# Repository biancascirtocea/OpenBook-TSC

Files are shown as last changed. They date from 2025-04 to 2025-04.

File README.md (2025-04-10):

# OpenBook Reader

## Descriere generala

Proiectul **OpenBook ESP32-C6** este o platforma hardware compacta si portabila, dedicata aplicatiilor embedded cu consum redus de energie. Este construit in jurul microcontrollerului **ESP32-C6-WROOM-1-N8**, oferind conectivitate wireless (Wi-Fi 6 si BLE 5.0) si numeroase interfete pentru senzori si module externe. Platforma include un e-paper display, senzor de mediu BME688, modul RTC DS3231SN, memorie externa NOR Flash de 64MB, slot pentru SD card si sistem de alimentare cu baterie LiPo cu incarcator si indicator de nivel.

---

## Diagramă bloc

430666922-ddbbfbfa-e72c-47d6-83a7-a39f880fc3e8

---

## BOM - Bill of Materials

# BOM (Bill Of Materials)

| Componenta | Link | Datasheet |
|---|---|---|
| BUTTON | [Model](https://industry.panasonic.com/global/en/products/control/switch/light-touch/number/evqpuj02k) | [Datasheet](https://www.lcsc.com/datasheet/lcsc_datasheet_2201121800_PANASONIC-EVQPUJ02K_C2936858.pdf) |
| CAPACITOR | [Model](https://componentsearchengine.com/part-view/R0402%201%25%20100%20K%20(RC0402FR-07100KL)/YAGEO) | [Datasheet](//efaidnbmnnnibpcajpcglclefindmkaj/https://www.resistor.com/assets/pdf/0402tstd.pdf) |
| CPH3225A | [Model](https://www.snapeda.com/parts/CPH3225A/Seiko+Instruments/view-part/?ref=eda) | [Datasheet](https://octopart.com/datasheet/cph3225a-seiko-25340571) |
| EVQPUJ02K | [Model](https://industry.panasonic.com/global/en/products/control/switch/light-touch/number/evqpuj02k) | [Datasheet](https://www.lcsc.com/datasheet/lcsc_datasheet_2201121800_PANASONIC-EVQPUJ02K_C2936858.pdf) |
| KP-1608SURCK | [Model](https://www.snapeda.com/parts/KP-1608SURCK/Kingbright/view-part/?ref=search&t=LED%200603) | [Datasheet](//efaidnbmnnnibpcajpcglclefindmkaj/https://media.elv.com/file/107153_led_surck1608_data.pdf) |
| USBLC6-2SC6Y | [Model](https://www.snapeda.com/parts/USBLC6-2SC6Y/STMicroelectronics/view-part/?ref=eda) | [Datasheet](https://www.digikey.com/en/htmldatasheets/production/1375342/0/0/1/usblc6-2sc6y) |
| SD0805S020S1R0 | [Model](https://ro.mouser.com/ProductDetail/KYOCERA-AVX/SD0805S020S1R0?qs=jCA%252BPfw4LHbpkAoSnwrdjw%3D%3D) | [Datasheet](https://www.alldatasheet.com/view.jsp?Searchword=SD0805S&sField=2) |
| PGB1010603MR | [Model](https://www.snapeda.com/parts/PGB1010603MR/Littelfuse/view-part/?ref=eda) | [Datasheet](https://www.alldatasheet.com/view.jsp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) |
| BD5229G-TR  | [Model](https://componentsearchengine.com/part-view/BD5229G-TR/ROHM%20Semiconductor) | [Datasheet](https://www.lcsc.com/datasheet/lcsc_datasheet_2201131330_ROHM-Semicon-BD5229G-TR_C962636.pdf) |
| XC6220A331MR-G | [Model](https://componentsearchengine.com/part-view/XC6220A331MR-G/Torex) | [Datasheet](https://www.alldatasheet.com/view.jsp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) |
| XC6220A331MR-G | [Model](https://componentsearchengine.com/part-view/XC6220A331MR-G/Torex) | [Datasheet](https://www.alldatasheet.com/view.jsp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) |
| USB4110-GF-A  | [Model](https://componentsearchengine.com/part-view/USB4110-GF-A/GCT%20(GLOBAL%20CONNECTOR%20TECHNOLOGY)) | [Datasheet](//efaidnbmnnnibpcajpcglclefindmkaj/https://gct.co/files/drawings/usb4110.pdf) |
| Adafruit | [Model](https://eu.mouser.com/ProductDetail/Adafruit/4208?qs=PzGy0jfpSMtbScLbr0L5dw%3D%3D) | [Datasheet](https://www.arrow.com/en/manufacturers/adafruit-industries/datasheets) |
| Bobina | [Model](https://store.comet.srl.ro/Catalogue/Product/43497/) | [Datasheet](https://www.scribd.com/document/814581278/Datasheet-Bobina) |
| PFMF | [Model](https://www.mouser.co.uk/ProductDetail/EPCOS-TDK/B72520T0350K062?qs=dEfas%2FXlABIszF52uu7vrg%3D%3D) | [Datasheet](https://ro.mouser.com/c/ds/circuit-protection/thermistors/resettable-fuses-pptc/?m=Schurter&series=PFMF) |
| DMG2305UX-7 | [Model](https://componentsearchengine.com/part-view/DMG2305UX-7/Diodes%20Incorporated) | [Datasheet](//efaidnbmnnnibpcajpcglclefindmkaj/https://www.mouser.com/datasheet/2/115/DMG2305UX-266242.pdf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) |
| Si1308EDL-T1-GE3 | [Model](https://componentsearchengine.com/part-view/SI1308EDL-T1-GE3/Vishay) | [Datasheet](https://www.alldatasheet.com/view.jsp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) |
| R0402 | [Model](https://componentsearchengine.com/part-view/R0402%201%25%20100%20K%20(RC0402FR-07100KL)/YAGEO) | [Datasheet](//efaidnbmnnnibpcajpcglclefindmkaj/https://www.resistor.com/assets/pdf/0402tstd.pdf) |
| BME680 | [Model](https://www.snapeda.com/parts/BME680/Bosch/view-part/?welcome=home) | [Datasheet](//efaidnbmnnnibpcajpcglclefindmkaj/https://www.bosch-sensortec.com/media/boschsensortec/downloads/datasheets/bst-bme680-ds001.pdf) |
| SMD Solder | [Model](https://grabcad.com/library/solder-jumpers-1) | [Datasheet]() |
| W25Q512JVEIQ | [Model](https://www.snapeda.com/parts/ESP32-C6-WROOM-1-N8/Espressif+Systems/view-part/?ref=eda) | [Datasheet](//efaidnbmnnnibpcajpcglclefindmkaj/https://www.mouser.com/datasheet/2/949/W25Q512JV_SPI_RevB_06252019_KMS-2487502.pdf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) |
| ESP32-C6-WROOM-1-N8 | [Model](https://www.snapeda.com/parts/ESP32-C6-WROOM-1-N8/Espressif+Systems/view-part/?ref=eda) | [Datasheet](//efaidnbmnnnibpcajpcglclefindmkaj/https://www.mouser.com/catalog/specsheets/Espressif_ESP32_C6_WROOM_1%20_Datasheet_V0.1_PRELIMINARY_en.pdf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) |
| DS3231SN# | [Model](https://www.snapeda.com/parts/DS3231SN%23/Analog+Devices/view-part/?ref=eda) | [Datasheet](https://www.alldatasheet.com/view.jsp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) |
| MAX17048G+T10 | [Model](https://www.snapeda.com/parts/MAX17048G+T10/Analog+Devices/view-part/?ref=eda) | [Datasheet](https://www.alldatasheet.com/view.jsp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) |
| MCP73831T-5ACI/OT | [Model](https://www.mouser.co.uk/ProductDetail/Microchip-Technology/MCP73831T-5ACI-OT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) | [Datasheet](//efaidnbmnnnibpcajpcglclefindmkaj/https://ww1.microchip.com/downloads/en/DeviceDoc/MCP73831-Family-Data-Sheet-DS20001984H.pdf) |

---

## Functionalitate Hardware

### ESP32-C6:
ESP32-C6 este unitatea centrală de procesare responsabilă pentru toate operațiunile sistemului, comunicarea cu senzorii și modulele, și gestionarea energiei. (Frecvență - 160 MHz)

- Microcontroller principal, gestioneaza toate perifericele.
- Comunicatii: Wi-Fi 6, BLE 5.0
- GPIO-uri multiple configurabile pentru I2C, SPI, UART.
Arhitectură: RISC-V 32-bit

### RTC - DS3231SN:
- Timp real precis,chiar si cand este sistemul oprit, compensare de temperatură, baterie de backup
- I2C comun cu BME688.

### Senzor BME688:
- Masoara temperatura, umiditate, presiune si VOC (gaze).
- I2C: conectat la aceeasi magistrala cu RTC.
- Monitorizarea condițiilor ambientale pentru ajustarea automată a afișajului și urmărirea datelor de mediu

### E-Paper Display:
- Afișaj pasiv cu consum foarte redus.
- Control prin SPI + pini de control (RST, DC, BUSY).
- Dimensiune: 7.5 inches
- Resolutie: 800x480 pixels

### Memorie NOR Flash 64MB:
- W25Q512JVEIQ - memorie externa SPI pentru loguri sau grafica e-paper.
- Memorie externă pentru loguri sau stocare grafică e-paper

### Slot SD Card:
- Alternativa pentru stocare loguri mari.
- Controlat tot prin SPI (CS separat).
- Memorie Flash externă: W25Q512JVEIQ - 64MB NOR Flash
- Memorie externă pentru loguri sau stocare grafică e-paper

### Sistem de alimentare:
- Intrare USB-C + protecție ESD.
- Capacitate: 3.7V, minim 1500mAh
- MCP73831 pentru incarcarea bateriei LiPo.
- MAX17048 pentru citire nivel incarcare baterie (via I2C).
- Tensiune de intrare: 5V prin conector USB-C
- Regulator de tensiune: LDO pentru stabilizare la 3.3V.

### Conector USB-C și Protecție ESD
- Funcționalitate: Asigură alimentarea cu energie și capacitatea de transfer de date
- Protecție: Protecție ESD integrată și diodă Schottky pentru siguranța la polaritate inversă

###  Butoane și Interfața Utilizator
- Butoane tactile pentru navigare și control.

### Extensii:
- Header Qwiic pentru conectarea de senzori I2C plug-and-play.
- Posibilitate de extindere prin interfețele GPIO disponibile

### Interfețe de Comunicare
GPIO: Utilizat pentru controlul butoanelor și operațiuni generale I/O
SPI: Utilizat pentru cardul SD, memoria flash externă și afișajul e-paper
I2C: Utilizat pentru senzorul de mediu BME688 și modulul RTC DS3231SN
UART: Utilizat pentru debugging și comunicare serială
Wi-Fi și Bluetooth: Furnizate de ESP32-C6, permițând conectivitate wireless

## Supervisori de Tensiune și Reset
Circuit de monitorizare a tensiunii pentru reset sigur
Indicator nivel încărcare baterie

## Dimensiuni și Specificații Fizice
Dimensiuni placă PCB: aproximativ 92 x 54 mm
Formă: PCB cu design compact și eficient pentru integrare în carcasă

## Caracteristici Principale
Consum ultra-redus de energie datorită afișajului e-paper și managementului avansat al energiei
Conectivitate wireless completă prin Wi-Fi 6 și Bluetooth 5.0
Monitorizare a condițiilor de mediu în timp real
Design modular pentru extindere ușoară și personalizare
Suport pentru stocare externă prin card microSD
Autonomie extinsă a bateriei

## Caracteristici Software
Compatibil cu diverse formate de cărți electronice
Interfață utilizator intuitivă pentru navigare și citire
Capacitate de sincronizare wireless cu dispozitive și servicii externe
Personalizare avansată a experienței de citire
Monitorizare și înregistrare a datelor de mediu

## Note de Design
Layout PCB optimizat pentru minimizarea interferențelor și maximizarea eficienței energetice.
Componente selectate pentru consum redus de energie și performanță fiabilă.
Soluții de protecție integrate pentru componente sensibile.
Design compact pentru portabilitate ridicată.

---

## Conexiuni catre ESP32-C6

| Pin ESP32-C6 | Funcție | Conectat la |
|---|---|---|
| IO0 (MOSI) | SPI MOSI | E-paper, SD Card, Flash |
| IO1 (MISO) | SPI MISO | SD Card, Flash |
| IO2 (CLK) | SPI CLK | Toate SPI devices |
| IO3 (CS) | SPI CS | E-paper Display |
| IO4 | SPI CS | W25Q512 NOR Flash |
| IO5 | SPI CS | SD Card |
| IO6 | I2C SDA | BME688, RTC, Fuel Gauge |
| IO7 | I2C SCL | BME688, RTC, Fuel Gauge |
| IO8 | Buton Boot | GND prin rezistor |
| IO10, IO11 | UART0 | Programare / Debug |
| EN | Enable MCU | Legat la 3V3 prin pullup |

## Alte Observatii
- PCB Layout: oferă separare clară între power și logică digitală.

- Posibil montaj în carcasă 3D: puncte de prindere pentru șuruburi M2 pe marginile PCB.

- Ajustări Footprint : Bobina 744043680 și U4 (MAX17048G+T10) au fost ajustate pentru a preveni erori DRC.

- Restricții de Rutare Power
  * Majoritatea traseelor de alimentare sunt pe stratul superior
  * Necesitate de rutare parțială pe stratul inferior pentru unele trasee de alimentare
  * Plan de masă prezent pe ambele straturi pentru reducerea zgomotului și îmbunătățirea integrității semnalului

- Plasarea Componentelor
  * Layout-ul respectă design-ul de referință pentru eficiență optimă
  * Bateria se potrivește perfect lângă PCB în interiorul carcasei

- Puncte de Test : Test pads prezente pentru debugging pe semnale SPI/I2C/Power

- Număr și Amplasare Via-uri : Designul include 0 vias-uri pe traseul de putere.

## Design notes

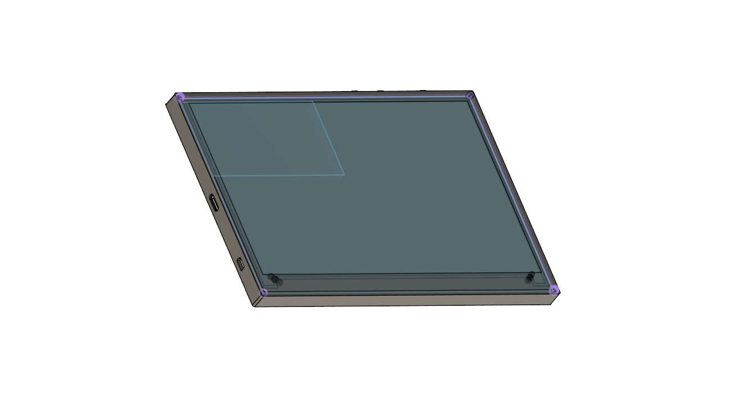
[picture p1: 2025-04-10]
Images/OpenBook_Reader_3D_Front2.png

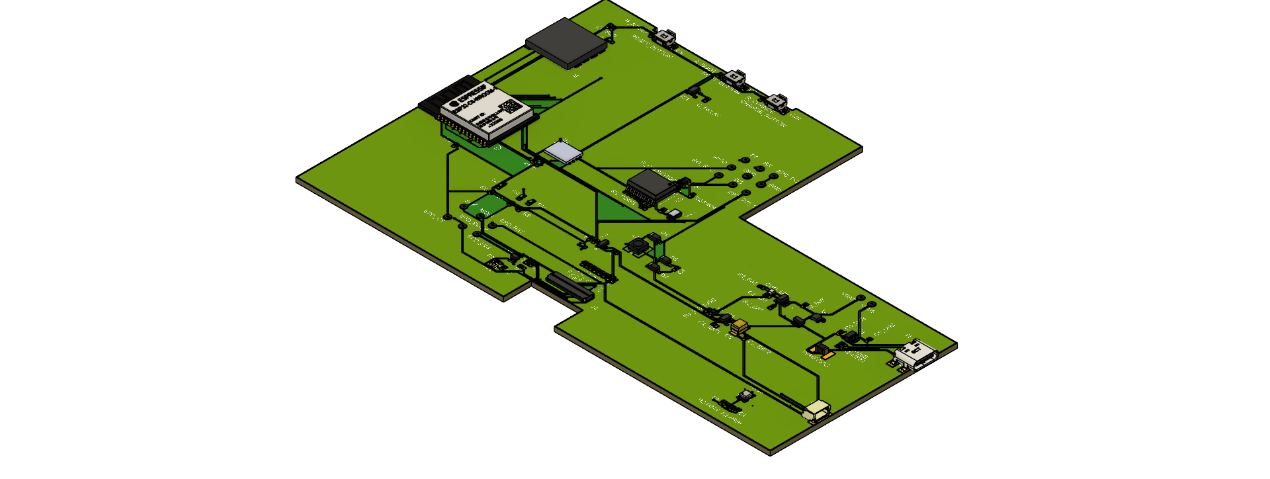
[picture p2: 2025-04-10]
Images/Face_3D_PCB.png

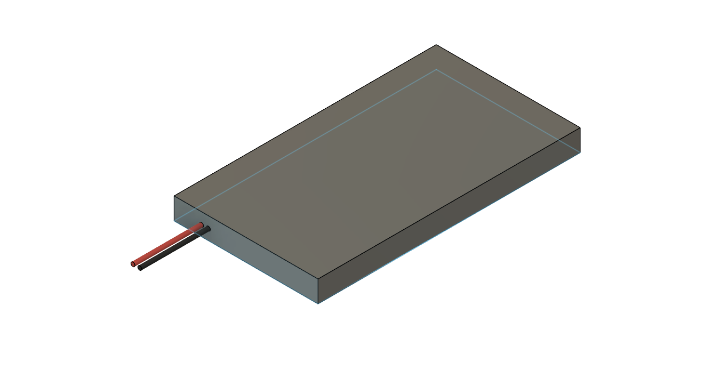
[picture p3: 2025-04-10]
Images/battery.png

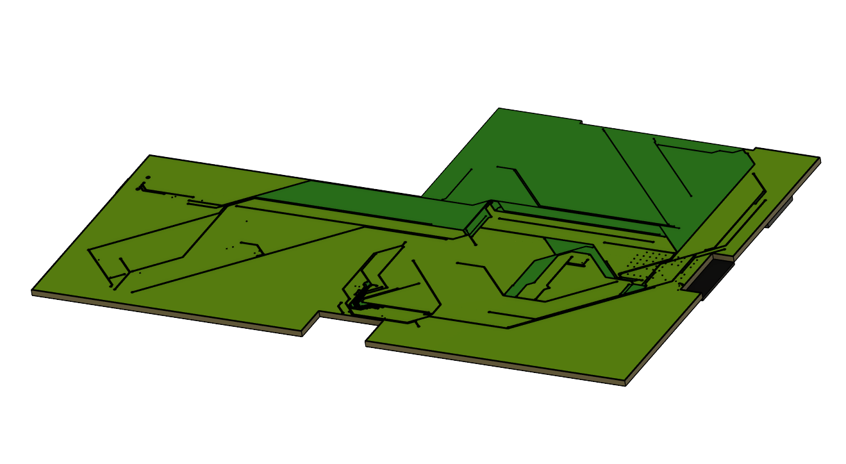
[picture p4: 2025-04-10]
Images/Back_3D_PCB.png

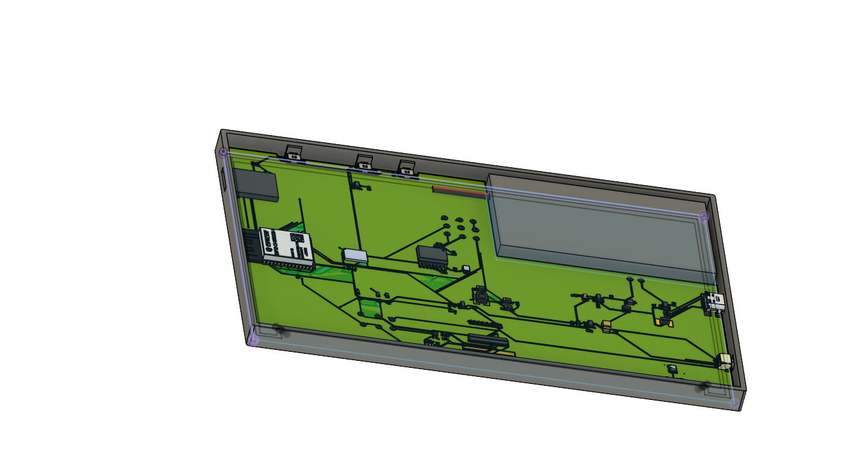
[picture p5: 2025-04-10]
Images/OpenBook_Reader_3D_Front1.png

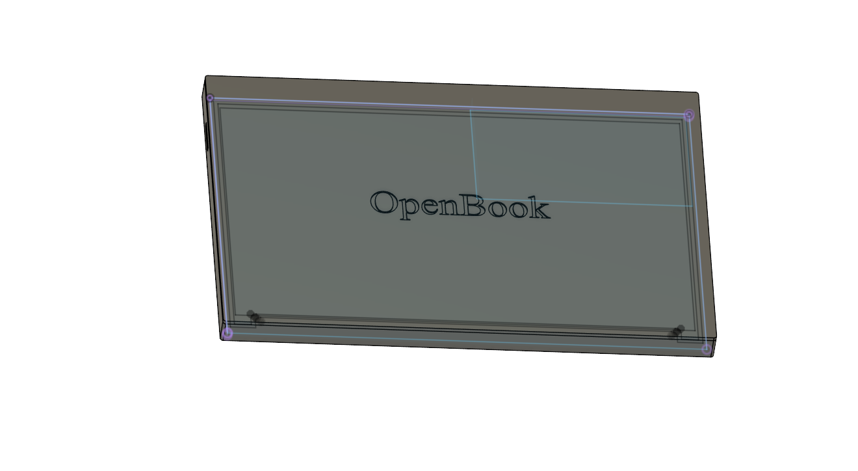
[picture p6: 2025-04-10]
Images/OpenBook_Reader_3D_Back2.png

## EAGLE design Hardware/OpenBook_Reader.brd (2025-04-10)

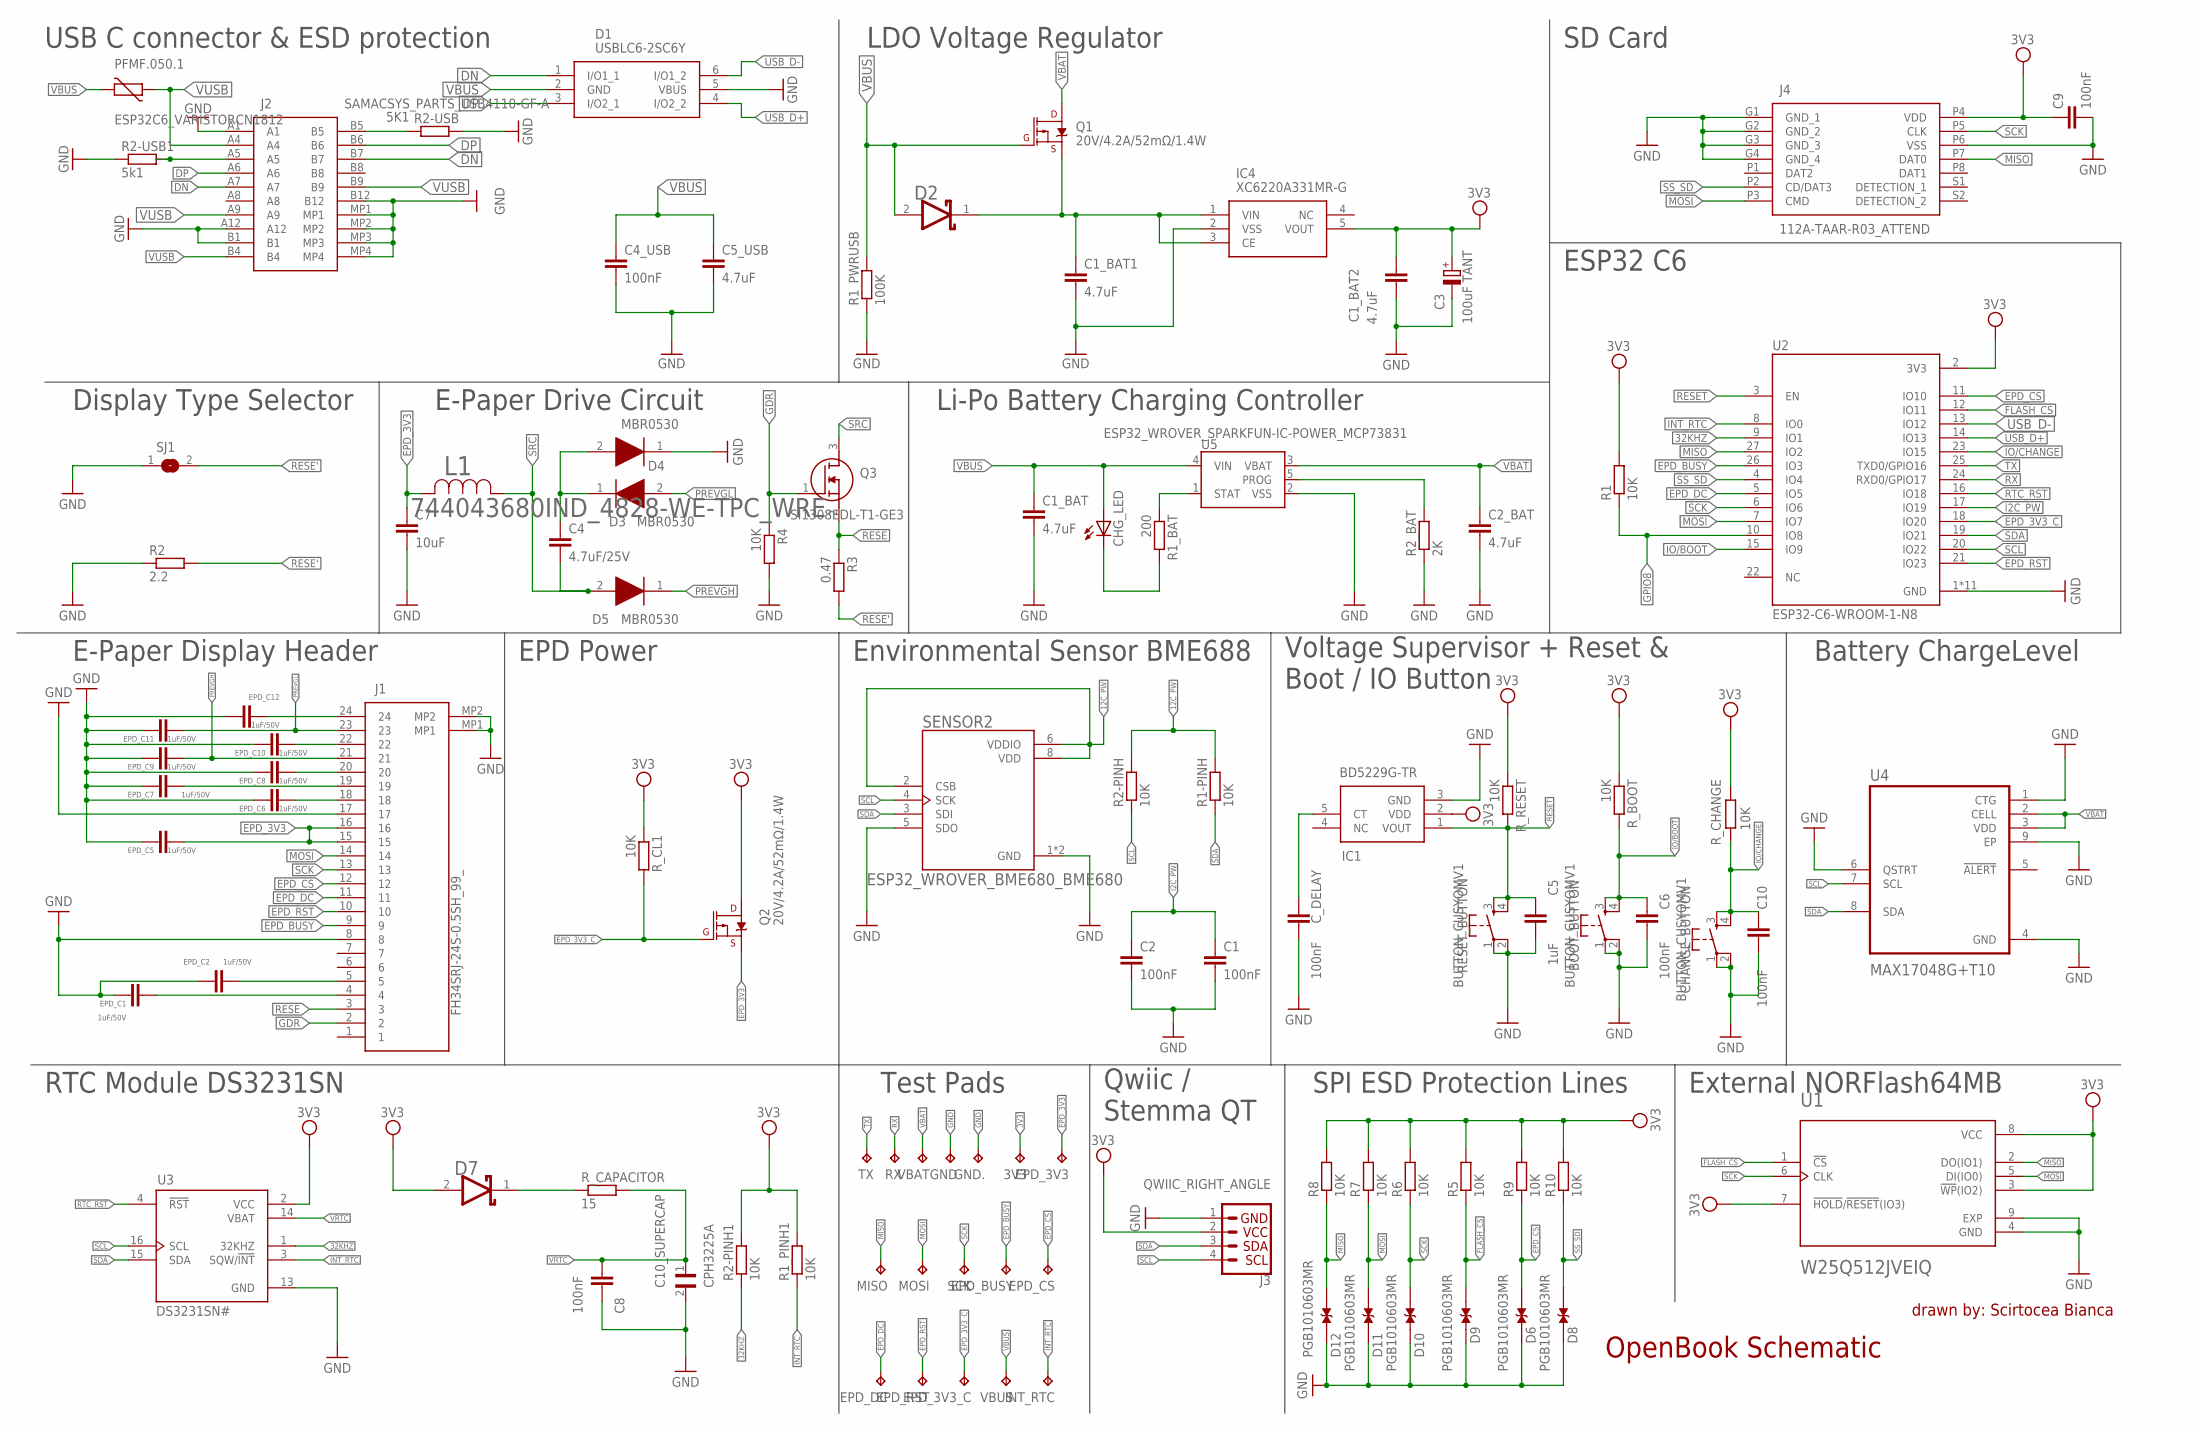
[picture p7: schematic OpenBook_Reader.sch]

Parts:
3V3: TPTP20R; TP20R
BOOT_BUTTON: BUTTON_CUSYOMV1; MYBUTTON
C1, C2, C4_USB, C6, C8, C9, C10: 100nF; EAGLE-LTSPICE_C0402
C1_BAT, C1_BAT1, C1_BAT2, C2_BAT, C5_USB: 4.7uF; EAGLE-LTSPICE_C0402
C3: 100uF TANT; RCL_CT3528
C4: 4.7uF/25V; EAGLE-LTSPICE_C0402
C5: 1uF; EAGLE-LTSPICE_C0402
C7: 10uF; EAGLE-LTSPICE_C0402
C10_SUPERCAP: CPH3225A; CAPCP3225X100N
CHANGE_BUTTON: BUTTON_CUSYOMV1; MYBUTTON
CHG_LED: ADAFRUIT_LEDCHIP-LED0603; ADAFRUIT_CHIP-LED0603
C_DELAY: 100nF; EAGLE-LTSPICE_C0402
D1: USBLC6-2SC6Y; SOT95P280X145-6N
D2, D7: ESP32_WROVER_AVX---SD0805S020S1R0_AVX_SD0805S020S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; ESP32_WROVER_AVX---SD0805S020S1R0_AVX_SD0805S020S1R0_0
D3, D4, D5: MBR0530; SOD3716X135N
D6, D8, D9, D10, D11, D12: PGB1010603MR; DIOC1608X36N
EPD_3V3, EPD_3V3_C: TPTP20R; TP20R
EPD_BUSY: TPTP20R; TP20R
EPD_C1, EPD_C2, EPD_C5, EPD_C6, EPD_C7, EPD_C8, EPD_C9, EPD_C10, EPD_C11, EPD_C12: 1uF/50V; EAGLE-LTSPICE_C0402
EPD_CS: TPTP20R; TP20R
EPD_DC: TPTP20R; TP20R
EPD_RST: TPTP20R; TP20R
GND, GND.: TPTP20R; TP20R
IC1: BD5229G-TR; SOT95P280X125-5N
IC4: XC6220A331MR-G; SOT95P280X120-5N
INT_RTC: TPTP20R; TP20R
J1: FH34SRJ-24S-0.5SH_99_; FH34SRJ24S05SH99
J2: SAMACSYS_PARTS_USB4110-GF-A; SAMACSYS_PARTS_USB4110GFA
J3: QWIIC_RIGHT_ANGLE; JST04_1MM_RA
J4: 112A-TAAR-R03_ATTEND; 112ATAARR03ATTEND
L1: 744043680IND_4828-WE-TPC_WRE; IND_4828-WE-TPC_WRE
MISO: TPTP20R; TP20R
MOSI: TPTP20R; TP20R
PFMF.050.1: ESP32C6_VARISTORCN1812; ESP32C6_VARISTOR_CT/CN1812
Q1, Q2: 20V/4.2A/52mΩ/1.4W; ESP32_WROVER_SPARKFUN-DISCRETESEMI_SOT23-3
Q3: SI1308EDL-T1-GE3; SOT65P210X110-3N
R1, R1-PINH, R1_PINH1, R2-PINH, R2-PINH1, R4, R5, R6, R7, R8, R9, R10: 10K; ESP32_WROVER_EAGLE-LTSPICE_R0402
R1_BAT: 200; ESP32_WROVER_EAGLE-LTSPICE_R0402
R1_PWRUSB: 100K; ESP32_WROVER_EAGLE-LTSPICE_R0402
R2: 2.2; ESP32_WROVER_EAGLE-LTSPICE_R0402
R2-USB: 5K1; ESP32_WROVER_EAGLE-LTSPICE_R0402
R2-USB1: 5k1; ESP32_WROVER_EAGLE-LTSPICE_R0402
R2_BAT: 2K; ESP32_WROVER_EAGLE-LTSPICE_R0402
R3: 0.47; ESP32_WROVER_EAGLE-LTSPICE_R0402
RESET_BUTTON: BUTTON_CUSYOMV1; MYBUTTON
RX: TPTP20R; TP20R
R_BOOT: 10K; ESP32_WROVER_EAGLE-LTSPICE_R0402
R_CAPACITOR: 15; ESP32_WROVER_EAGLE-LTSPICE_R0402
R_CHANGE: 10K; ESP32_WROVER_EAGLE-LTSPICE_R0402
R_CL1: 10K; ESP32_WROVER_EAGLE-LTSPICE_R0402
R_RESET: 10K; ESP32_WROVER_EAGLE-LTSPICE_R0402
SCK: TPTP20R; TP20R
SENSOR2: ESP32_WROVER_BME680_BME680; ESP32_WROVER_BME680_PSON80P300X300X100-8N
SJ1: SJ
TX: TPTP20R; TP20R
U1: W25Q512JVEIQ; SON127P600X800X80-9N
U2: ESP32-C6-WROOM-1-N8; XCVR_ESP32-C6-WROOM-1-N8
U3: DS3231SN#; SOIC127P1032X265-16N
U4: MAX17048G+T10; SON50P200X200X80-9N
U5: ESP32_WROVER_SPARKFUN-IC-POWER_MCP73831; ESP32_WROVER_SPARKFUN-IC-POWER_SOT23-5
VBAT: TPTP20R; TP20R
VBUS: TPTP20R; TP20R

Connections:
3V3: 3V3.TP, C1_BAT2.1, C3.+, C9.1, D7.2 (ANODE), IC1.2 (VDD), IC4.5 (VOUT), J3.2, J4.P4 (VDD), Q2.3 (D), R1.2, R1_PINH1.2, R2-PINH1.2, R5.2, R6.2, R7.2, R8.2, R9.2, R10.2, R_BOOT.1, R_CHANGE.1, R_CL1.1, R_RESET.1, U1.3 (!WP!(IO2)), U1.7 (!HOLD!/!RESET!(IO3)), U1.8 (VCC), U2.2 (3V3), U3.2 (VCC)
12C_PW: R1-PINH.2, R2-PINH.2, SENSOR2.2 (CSB), SENSOR2.6 (VDDIO), SENSOR2.8 (VDD)
32KHZ: R2-PINH1.1, U2.9 (IO1), U3.1 (32KHZ)
DN: D1.1 (I/O1_1), J2.A7, J2.B7
DP: D1.3 (I/O2_1), J2.A6, J2.B6
EPD_3V3: C7.1, EPD_3V3.TP, EPD_C5.2, J1.15, J1.16, L1.2, Q2.2 (S)
EPD_3V3_C: EPD_3V3_C.TP, Q2.1 (G), R_CL1.2, U2.18 (IO20)
EPD_BUSY: EPD_BUSY.TP, J1.9, U2.26 (IO3)
EPD_CS: D6.2, EPD_CS.TP, J1.12, R9.1, U2.11 (IO10)
EPD_DC: EPD_DC.TP, J1.11, U2.5 (IO5)
EPD_RST: EPD_RST.TP, J1.10, U2.21 (IO23)
FLASH_CS: D9.2, R5.1, U1.1 (!CS), U2.12 (IO11)
GDR: J1.2, Q3.1 (G), R4.1
GND: BOOT_BUTTON.1, BOOT_BUTTON.2, C1.2, C1_BAT.2, C1_BAT1.2, C1_BAT2.2, C2.2, C2_BAT.2, C3.-, C4_USB.2, C5.2, C5_USB.2, C6.2, C7.2, C8.2, C9.2, C10.2, C10_SUPERCAP.2, CHANGE_BUTTON.1, CHANGE_BUTTON.2, C_DELAY.2, D1.5 (VBUS), D4.1 (K), D6.1, D8.1, D9.1, D10.1, D11.1, D12.1, EPD_C1.1, EPD_C2.1, EPD_C5.1, EPD_C6.1, EPD_C7.1, EPD_C8.1, EPD_C9.1, EPD_C10.1, EPD_C11.1, EPD_C12.1, GND.TP, GND..TP, IC1.3 (GND), IC4.2 (VSS), J1.8, J1.17, J1.MP1, J1.MP2, J2.A1, J2.A12, J2.B1, J2.B12, J2.MP1, J2.MP2, J2.MP3, J2.MP4, J3.1, J4.G1 (GND_1), J4.G2 (GND_2), J4.G3 (GND_3), J4.G4 (GND_4), J4.P6 (VSS), R1_PWRUSB.1, R2.1, R2-USB.2, R2-USB1.1, R2_BAT.1, R4.2, RESET_BUTTON.1, RESET_BUTTON.2, SENSOR2.1 (GND), SENSOR2.5 (SDO), SENSOR2.7 (GND), SJ1.1, U1.4 (GND), U1.9 (EXP), U2.1 (GND), U2.28 (GND), U2.29_1 (GND), U2.29_2 (GND), U2.29_3 (GND), U2.29_4 (GND), U2.29_5 (GND), U2.29_6 (GND), U2.29_7 (GND), U2.29_8 (GND), U2.29_9 (GND), U3.13 (GND), U4.1 (CTG), U4.4 (GND), U4.6 (QSTRT), U4.9 (EP), U5.2 (VSS)
GPIO8: R1.1, U2.10 (IO8)
I2C_PW: C1.1, C2.1, U2.17 (IO19)
INT_RTC: INT_RTC.TP, R1_PINH1.1, U2.8 (IO0), U3.3 (SQW/!INT)
IO/BOOT: BOOT_BUTTON.3, BOOT_BUTTON.4, C6.1, R_BOOT.2, U2.15 (IO9)
IO/CHANGE: C10.1, CHANGE_BUTTON.3, CHANGE_BUTTON.4, R_CHANGE.2, U2.23 (IO15)
MISO: D12.2, J4.P7 (DAT0), MISO.TP, R8.1, U1.2 (DO(IO1)), U2.27 (IO2)
MOSI: D11.2, J1.14, J4.P3 (CMD), MOSI.TP, R7.1, U1.5 (DI(IO0)), U2.7 (IO7)
unnamed: J2.A5, R2-USB1.2
unnamed: J2.B5, R2-USB.1
unnamed: C1_BAT1.1, D2.1 (CATHODE), IC4.1 (VIN), IC4.3 (CE), Q1.2 (S)
unnamed: CHG_LED.C, R1_BAT.2
unnamed: R1_BAT.1, U5.1 (STAT)
unnamed: EPD_C1.2, J1.4
unnamed: R2_BAT.2, U5.5 (PROG)
unnamed: C4.1, D3.1 (K), D4.2 (A)
unnamed: EPD_C2.2, J1.5
unnamed: EPD_C6.2, J1.18
unnamed: EPD_C7.2, J1.19
unnamed: EPD_C8.2, J1.20
unnamed: C_DELAY.1, IC1.5 (CT)
unnamed: EPD_C10.2, J1.22
unnamed: EPD_C12.2, J1.24
unnamed: D7.1 (CATHODE), R_CAPACITOR.1
PREVGH: D5.1 (K), EPD_C9.2, J1.21
PREVGL: D3.2 (A), EPD_C11.2, J1.23
RESE: J1.3, Q3.2 (S), R3.1
RESE': R2.2, R3.2, SJ1.2
RESET: C5.1, IC1.1 (VOUT), RESET_BUTTON.3, RESET_BUTTON.4, R_RESET.2, U2.3 (EN)
RTC_RST: U2.16 (IO18), U3.4 (!RST)
RX: RX.TP, U2.24 (RXD0/GPIO17)
SCK: D10.2, J1.13, J4.P5 (CLK), R6.1, SCK.TP, U1.6 (CLK), U2.6 (IO6)
SCL: J3.4, R2-PINH.1, SENSOR2.4 (SCK), U2.20 (IO22), U3.16 (SCL), U4.7 (SCL)
SDA: J3.3, R1-PINH.1, SENSOR2.3 (SDI), U2.19 (IO21), U3.15 (SDA), U4.8 (SDA)
SRC: C4.2, D5.2 (A), L1.1, Q3.3 (D)
SS_SD: D8.2, J4.P2 (CD/DAT3), R10.1, U2.4 (IO4)
TX: TX.TP, U2.25 (TXD0/GPIO16)
USB_D+: D1.4 (I/O2_2), U2.14 (IO13)
USB_D-: D1.6 (I/O1_2), U2.13 (IO12)
VBAT: C2_BAT.1, Q1.3 (D), U4.2 (CELL), U4.3 (VDD), U5.3 (VBAT), VBAT.TP
VBUS: C1_BAT.1, C4_USB.1, C5_USB.1, CHG_LED.A, D1.2 (GND), D2.2 (ANODE), PFMF.050.1.2, Q1.1 (G), R1_PWRUSB.2, U5.4 (VIN), VBUS.TP
VRTC: C8.1, C10_SUPERCAP.1, R_CAPACITOR.2, U3.14 (VBAT)
VUSB: J2.A4, J2.A9, J2.B4, J2.B9, PFMF.050.1.1

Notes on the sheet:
USB C connector & ESD protection
LDO Voltage Regulator
SD Card
ESP32 C6
Li-Po Battery Charging Controller
E-Paper Drive Circuit
Display Type Selector
E-Paper Display Header
EPD Power
Environmental Sensor BME688
Voltage Supervisor + Reset & Boot / IO Button
Battery ChargeLevel
RTC Module DS3231SN
Test Pads
Qwiic / Stemma QT
SPI ESD Protection Lines
External NORFlash64MB
OpenBook Schematic
drawn by: Scirtocea Bianca

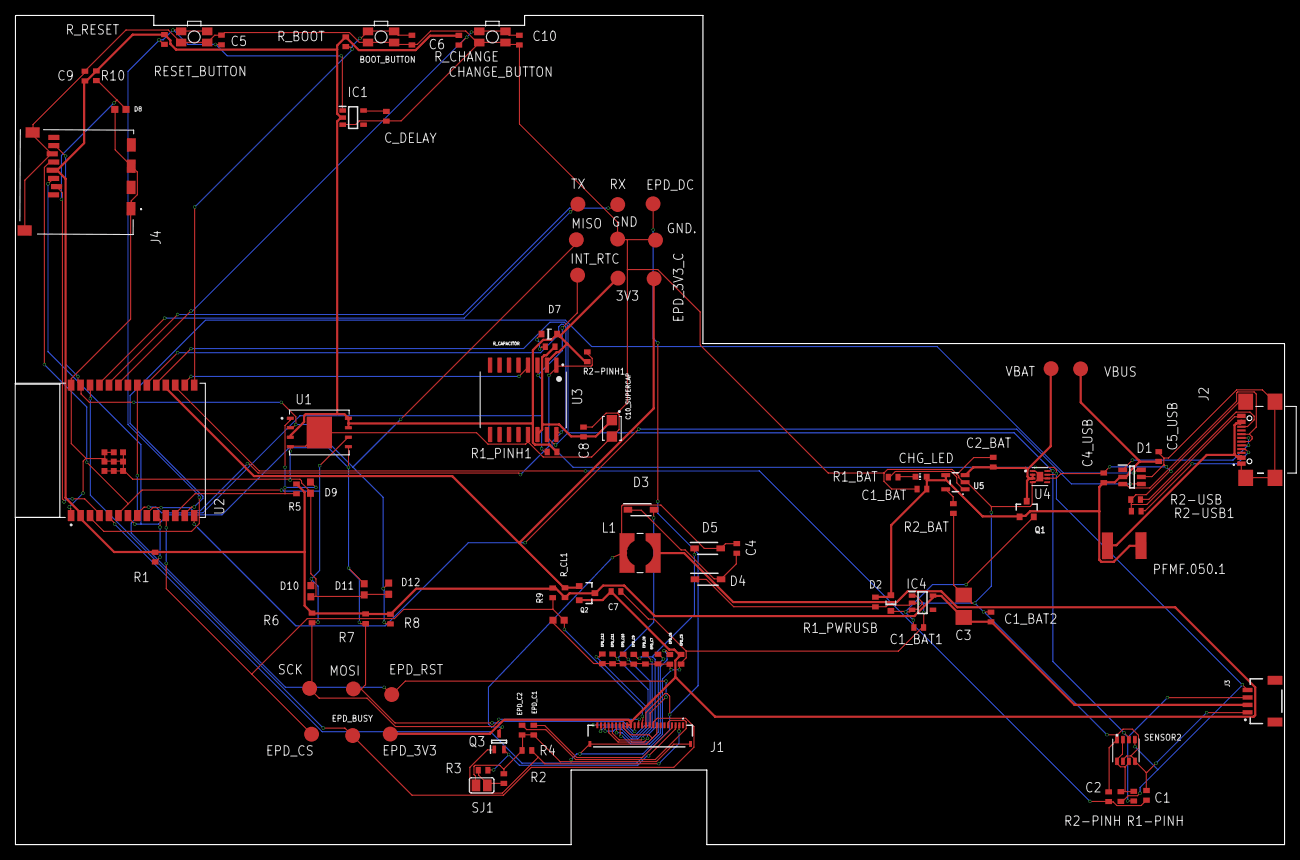
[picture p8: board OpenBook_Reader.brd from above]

Board: 2 copper layers, 170.2 x 111.2 mm, 103 parts (0 on the bottom side), 56 nets.

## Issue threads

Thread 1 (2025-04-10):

Lipsă valori rezistențe în fișierul schematic

marionistor, 2025-04-10:
**Descriere:**
În fișierul schematic lipsesc valorile pentru rezistențele R5, R6, R7, R8, R9 și R10.

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

**Impact:**
Lipsa acestor valori poate îngreuna înțelegerea circuitului și poate duce la erori în timpul asamblării sau simulării.

Closed 2025-04-10.

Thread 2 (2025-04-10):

TP-urile au denumiri generice

marionistor, 2025-04-10:
**Descriere:**
Tp-urile au denumiri generice precum TP1, TP2, TP11, etc. În schimb, ar trebui să fie etichetate pe silkscreen folosind numele semnalelor pe care le poartă (MISO, GND, RX, etc.).

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

**Impact:**
Denumirile generice îngreunează depanarea și testarea, deoarece nu este clar ce semnal corespunde fiecărui TP.

**Sugestie:**
**1.** Dă click dreapta pe fiecare TP și selectează **Properties**:

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

**2.** Schimbă numele pentru a se potrivi cu semnalul corespunzător:

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

Closed 2025-04-10.

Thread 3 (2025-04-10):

Planurile de masă nu acoperă complet suprafața PCB-ului

marionistor, 2025-04-10:
**Descriere:**
Planurile de masă de pe straturile top și bottom nu acoperă complet întreaga suprafață a PCB-ului. Sunt prezente mai multe zone neacoperite răspândite în diferite părți ale plăcii.

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

**Impact:**
Lipsa acoperirii complete a planurilor de masă poate duce la interferențe electromagnetice (EMI) și poate afecta performanța PCB-ului.

**Sugestie:**
**1.** Fă click dreapta pe marginea planului de masă și selectează **Proprietăți**:

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

**2.** Bifează **Orphans**:

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

Closed 2025-04-10.

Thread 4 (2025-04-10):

Denumirile pieselor se suprapun cu firele de conexiune

marionistor, 2025-04-10:
**Descriere:**
 În fișierul PCB unele texte (etichetări, descriere etc.) se suprapun cu firele de conexiune.

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

**Impact:**
Suprapunerea textului cu firele de conexiune poate reduce claritatea design-ului PCB-ului, făcându-l mai greu de citit și procesat.

**Sugestie:**
Denumirile pot fi mutate astfel încât să nu se suprapună cu firele de conexiune, iar dimensiunea textului poate fi micșorată.

Closed 2025-04-10.

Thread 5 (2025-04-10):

Lipsă denumiri coloane în PickAndPlace

marionistor, 2025-04-10:
**Descriere:**
Fișierul ar trebui să includă denumirile coloanelor pe prima linie.

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

**Impact:**
Fără denumirile coloanelor, fișierul poate duce la dificultăți în interpretarea corectă a datelor.

**Sugestie:**
Adaugă denumirile coloanelor corespunzătoare pe prima linie a fișierului PickAndPlace:  **Ref Des, Mid X (mm), Mid Y (mm), Rotation, LCSC Part Number**.

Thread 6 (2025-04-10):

Grosime PCB

marionistor, 2025-04-10:
**Descriere:**
Grosimea PCB-ului este de 1.6 mm, dar ar trebui să fie de 1 mm.

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

**Impact:**
O placă PCB mai groasă ar putea să nu se potrivească în carcasă sau să cauzeze probleme la asamblare.

**Sugestie:**
**1.** Dă click pe **Preferences** și selectează "Design Preferences":

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

**2.** Modifcă grosimea de la 1.6 mm la 1 mm:

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

Closed 2025-04-10.

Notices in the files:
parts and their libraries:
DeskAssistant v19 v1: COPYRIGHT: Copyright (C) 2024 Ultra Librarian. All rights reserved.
